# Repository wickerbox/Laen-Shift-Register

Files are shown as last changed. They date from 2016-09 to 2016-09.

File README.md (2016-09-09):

# Laen's Shift Register Demo v2

This is a project to convert Laen's shift register demonstration design into KiCad. The demo board provides eight output LEDs driven by an HC595 shift register with input press-buttons for data, clock, and latch.  

Each press of the clock button queues up the status of the data button; press the latch button to show the outputs. Reset everything by pressing the master reset button followed by the latch button.

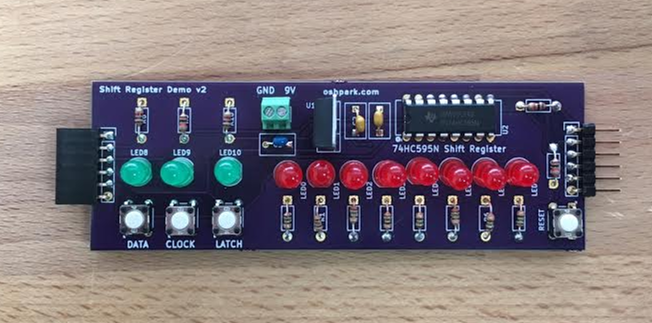
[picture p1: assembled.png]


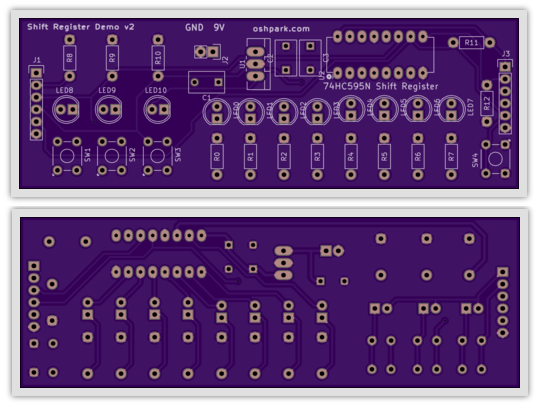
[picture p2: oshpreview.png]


The boards can be chained together by the connectors at each end. 

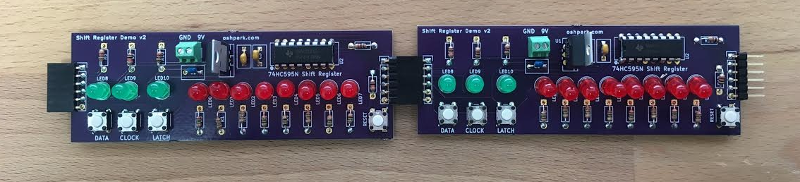
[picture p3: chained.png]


I've <a href="https://oshpark.com/projects/dWEtqIvz">shared the boards at OSH Park</a>, where you can buy a set of three for $28.85.

|Ref|Qty|Description|MF_Name|MF_PN|Digikey PN|
|---|---|---|---|-----|---|
|C1|1|CAP CER 0.33UF 50V X7R RADIAL|TDK|FK24X7R1H334K|445-5263-ND|
|C2-C3|2|CAP CER 0.1UF 50V C0G RADIAL|TDK|FK26C0G1H104J|445-8532-ND|
|J1|1|HEADER MALE 6POS TH 1x06 0.1”|Harwin|M20-9992046|952-1902-ND|
|J2|1|CONN TERM SCREW GREEN 2.54MM 2POS TH|OnShoreTech|OSTVN02A150|ED10561-ND|
|J3|1|HEADER FEMALE 6POS TH 1x06 0.1”|Harwin|M20-7820642|952-1808-ND|
|LED0-7|8|LED RED DIFF 5MM ROUND T/H|Marktech Opto|MT4118-HR-A|1125-1188-ND|
|LED8-10|3|LED GRN DIFF 5MM ROUND T/H|Marktech Opto|MT2118-G-A|1125-1184-ND|
|R0-R7|8|RES 150 OHM 1/4W 5% CF MINI|Stackpole|CFM14JT150R|S150QCT-ND|
|R8-R12|5|RES 1K OHM 1/4W 5% CF MINI|Stackpole|CFM14JT1K00|S1KQCT-ND|
|SW1-4|4| SWITCH TACTILE SPST-NO 0.05A 24V |Omron|B3F-1000|SW400-ND|
|U1|1|IC REG LDO 5V 1A NCP7805 TO220AB|ON Semi|NCP7805TG|NCP7805TGOS-ND|
|U2|1|IC 8-BIT SHIFT REGISTER 16-DIP|TI|SN74HC595N|296-1600-5-ND|

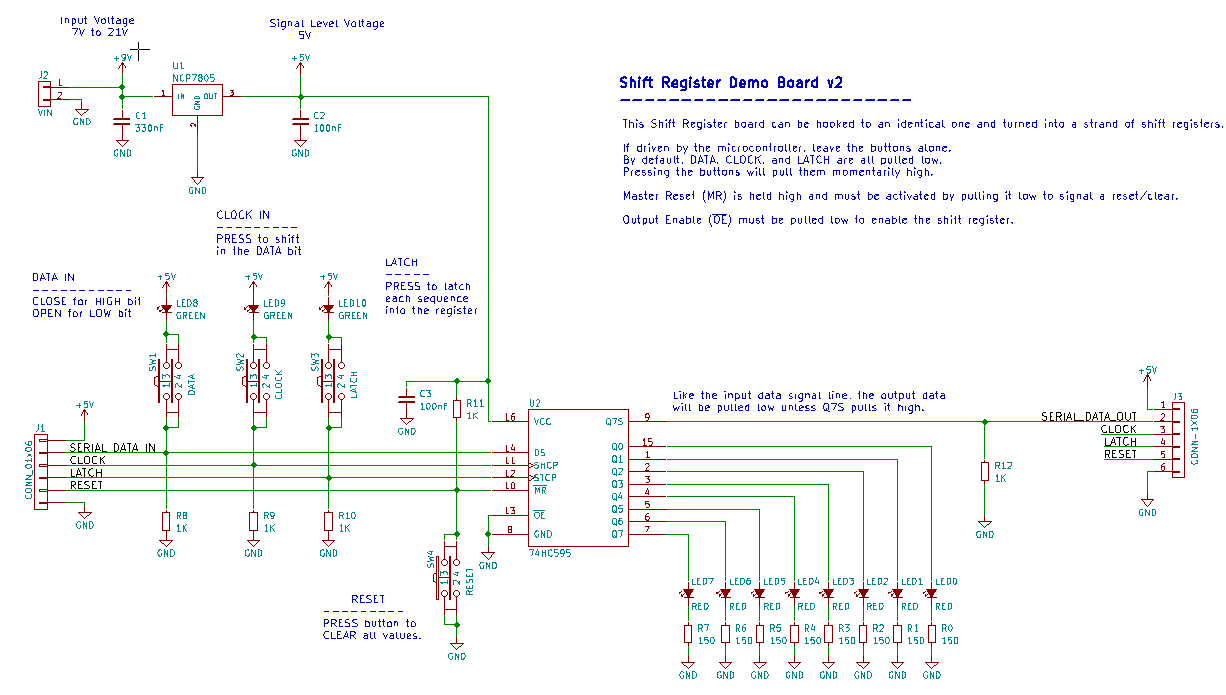
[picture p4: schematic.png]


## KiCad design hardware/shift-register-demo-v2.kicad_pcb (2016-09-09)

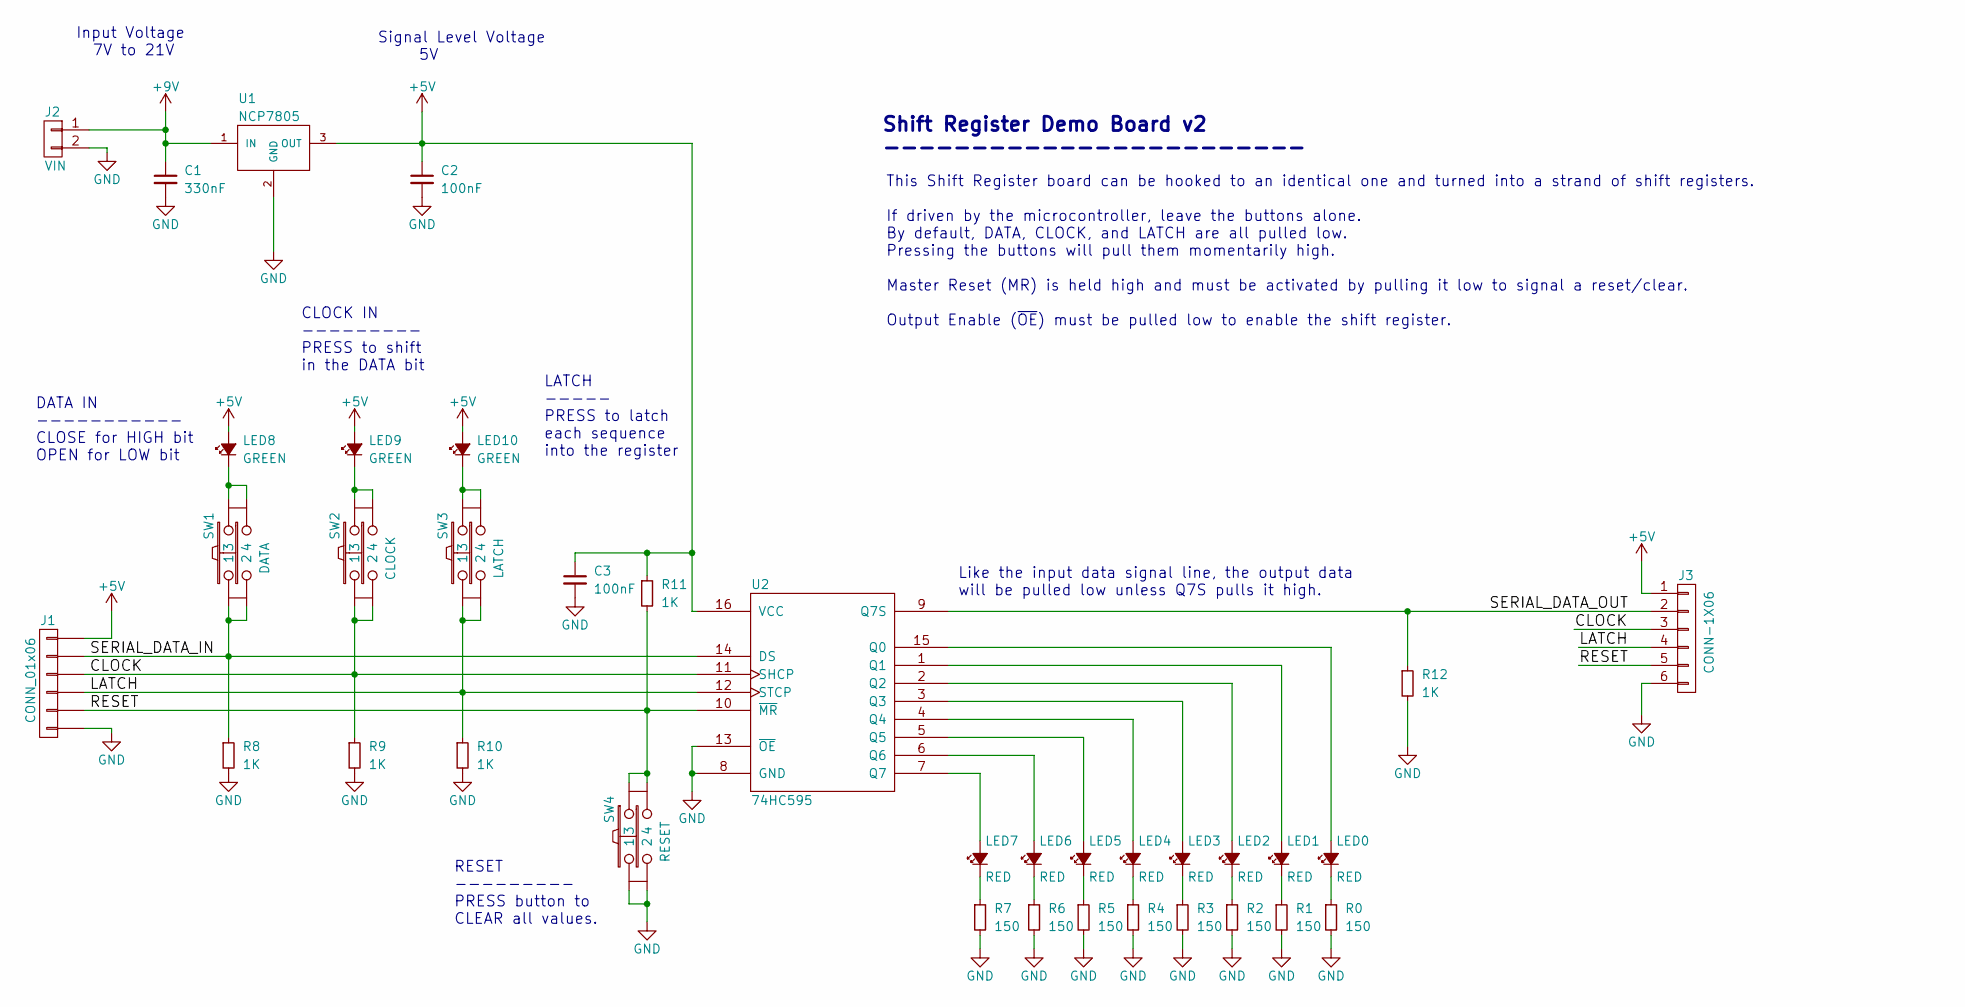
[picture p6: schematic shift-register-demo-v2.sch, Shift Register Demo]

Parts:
C1: 330nF; CAP-DISC-D7.5MM-P5MM
C2, C3: 100nF; CAP-DISC-D7.5MM-P5MM
J1: CONN_01x06; CONN-HEADER-STRAIGHT-P2.54MM-1x06
J2: VIN; CONN-ONSHORE-SCREW-GREEN-2PIN-TH
J3: CONN-1X06; CONN-HEADER-STRAIGHT-P2.54MM-1x06
LED0, LED1, LED2, LED3, LED4, LED5, LED6, LED7: RED; LED-D5MM-2PIN
LED8, LED9, LED10: GREEN; LED-D5MM-2PIN
R0, R1, R2, R3, R4, R5, R6, R7: 150; RES-CARBONFILM-7MM
R8, R9, R10, R11, R12: 1K; RES-CARBONFILM-7MM
SW1: DATA; SWITCH-OMRON-MOMENTARY-TH-B3F-10XX
SW2: CLOCK; SWITCH-OMRON-MOMENTARY-TH-B3F-10XX
SW3: LATCH; SWITCH-OMRON-MOMENTARY-TH-B3F-10XX
SW4: RESET; SWITCH-OMRON-MOMENTARY-TH-B3F-10XX
U1: NCP7805; TO-220-NEUTRAL123-VERT-LONGPADS
U2: 74HC595; DIP-16-W7.62MM-LONGPADS

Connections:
+5V: C2.1, C3.1, J1.1, J3.1, LED8.2, LED9.2, LED10.2, R11.1, U1.3 (OUT), U2.16 (VCC)
+9V: C1.1, J2.1, U1.1 (IN)
/CLOCK: J1.3, J3.3, R9.1, SW2.1, SW2.2, U2.11 (SHCP)
/LATCH: J1.4, J3.4, R10.1, SW3.1, SW3.2, U2.12 (STCP)
/RESET: J1.5, J3.5, R11.2, SW4.3, SW4.4, U2.10 (~MR)
/SERIAL_DATA_IN: J1.2, R8.1, SW1.1, SW1.2, U2.14 (DS)
/SERIAL_DATA_OUT: J3.2, R12.1, U2.9 (Q7S)
GND: C1.2, C2.2, C3.2, J1.6, J2.2, J3.6, R0.2, R1.2, R2.2, R3.2, R4.2, R5.2, R6.2, R7.2, R8.2, R9.2, R10.2, R12.2, SW4.1, SW4.2, U1.2 (GND), U2.8 (GND), U2.13 (~OE)
unnamed: LED0.1, R0.1
unnamed: LED0.2, U2.15 (Q0)
unnamed: LED1.1, R1.1
unnamed: LED1.2, U2.1 (Q1)
unnamed: LED2.1, R2.1
unnamed: LED2.2, U2.2 (Q2)
unnamed: LED3.1, R3.1
unnamed: LED3.2, U2.3 (Q3)
unnamed: LED4.1, R4.1
unnamed: LED4.2, U2.4 (Q4)
unnamed: LED5.1, R5.1
unnamed: LED5.2, U2.5 (Q5)
unnamed: LED6.1, R6.1
unnamed: LED6.2, U2.6 (Q6)
unnamed: LED7.1, R7.1
unnamed: LED7.2, U2.7 (Q7)
unnamed: LED8.1, SW1.3, SW1.4
unnamed: LED9.1, SW2.3, SW2.4
unnamed: LED10.1, SW3.3, SW3.4

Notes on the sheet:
This Shift Register board can be hooked to an identical one and turned into a strand of shift registers. If driven by the microcontroller, leave the buttons alone. By default, DATA, CLOCK, and LATCH are all pulled low. Pressing the buttons will pull them momentarily high. Master Reset (MR) is held 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
DATA IN ----------- CLOSE for HIGH bit OPEN for LOW bit
RESET --------- PRESS button to CLEAR all values.
Input Voltage 7V to 21V
LATCH ----- PRESS to latch each sequence into the register
Shift Register Demo Board v2 ------------------------
Like the input data signal line, the output data will be pulled low unless Q7S pulls it high.
Signal Level Voltage 5V
CLOCK IN --------- PRESS to shift in the DATA bit

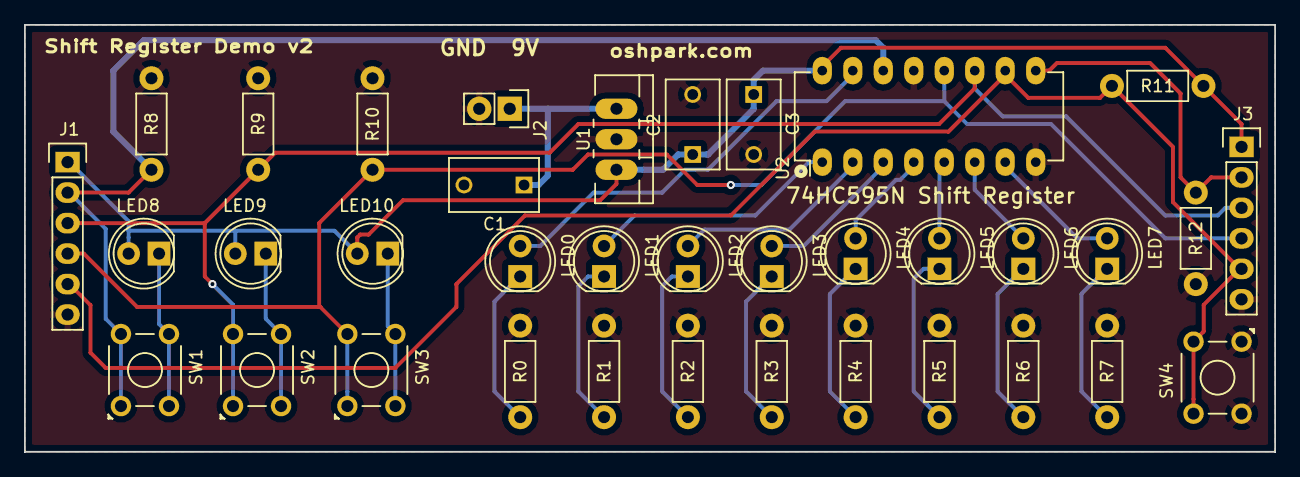
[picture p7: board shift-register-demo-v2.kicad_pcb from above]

Board: 2 copper layers, 104.1 x 35.6 mm, 36 parts (0 on the bottom side), 27 nets.

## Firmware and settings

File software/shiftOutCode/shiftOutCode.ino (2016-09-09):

//**************************************************************//
//  Name    : shiftOutCode, Hello World                                
//  Author  : Carlyn Maw,Tom Igoe, David A. Mellis 
//  Date    : 25 Oct, 2006    
//  Modified: 23 Mar 2010                                 
//  Version : 2.0                                             
//  Notes   : Code for using a 74HC595 Shift Register           //
//          : to count from 0 to 255                           
//****************************************************************

//Pin connected to ST_CP of 74HC595
int latchPin = 8;
//Pin connected to SH_CP of 74HC595
int clockPin = 12;
////Pin connected to DS of 74HC595
int dataPin = 11;

int i = 0;

void setup() {
  //set pins to output so you can control the shift register
  pinMode(latchPin, OUTPUT);
  pinMode(clockPin, OUTPUT);
  pinMode(dataPin, OUTPUT);
}

void loop() {
    digitalWrite(latchPin, LOW);
    digitalWrite(dataPin, HIGH);
    digitalWrite(clockPin, HIGH);
    digitalWrite(clockPin, LOW);
    digitalWrite(dataPin, LOW);
    digitalWrite(dataPin, HIGH);
    digitalWrite(clockPin, HIGH);
    digitalWrite(clockPin, LOW);
    digitalWrite(dataPin, LOW);
    digitalWrite(dataPin, HIGH);
    digitalWrite(clockPin, HIGH);
    digitalWrite(clockPin, LOW);
    digitalWrite(dataPin, LOW);
    digitalWrite(latchPin, HIGH);
    delay(500);
  for (i = 0; i<8; i++) {
    digitalWrite(latchPin, LOW);
    digitalWrite(dataPin, LOW);
    digitalWrite(clockPin, HIGH);
    digitalWrite(clockPin, LOW);
    digitalWrite(dataPin, LOW);
    digitalWrite(latchPin, HIGH);
    delay(500);
  }
 
}

void leds() {
  // count from 0 to 255 and display the number 
  // on the LEDs
  for (int numberToDisplay = 0; numberToDisplay < 256; numberToDisplay++) {
    // take the latchPin low so 
    // the LEDs don't change while you're sending in bits:
    digitalWrite(latchPin, LOW);
    // shift out the bits:
    shiftOut(dataPin, clockPin, MSBFIRST, numberToDisplay);  

    //take the latch pin high so the LEDs will light up:
    digitalWrite(latchPin, HIGH);
    // pause before next value:
    delay(500);
  }
}

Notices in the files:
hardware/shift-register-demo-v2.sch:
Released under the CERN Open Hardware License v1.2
